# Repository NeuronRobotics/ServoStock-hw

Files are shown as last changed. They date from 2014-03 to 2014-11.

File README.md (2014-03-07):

# Servo Stock Hardware Project#

## Download ##

Check out this repository and the Vitamins repository into the same working directory. 
This project will assume both repositories are in this same directory. 

$ cd ~/git/

$ git clone https://github.com/Technocopia/ServoStock-hw.git

$ git clone https://github.com/Technocopia/Vitamins.git

$ cd ServoStock-hw/ServoStock/

## Building ##

This project is built with a 3 copies of the print bed found in 

SingleAxisPrintBed.scad 

and one copy of

ExtruderPrintBed.scad

## Vitamins ##

The ServoStock uses standardized vitamin models found in the Vitamins project. These models refer to actual hardware that can not be printed. 

Parts lists can be found here:

https://docs.google.com/spreadsheet/ccc?key=0AvROWAz_jAGGdHdnakh3WWF6LXMtMFFtdWdrZkJVZVE&usp=drive_web#gid=3

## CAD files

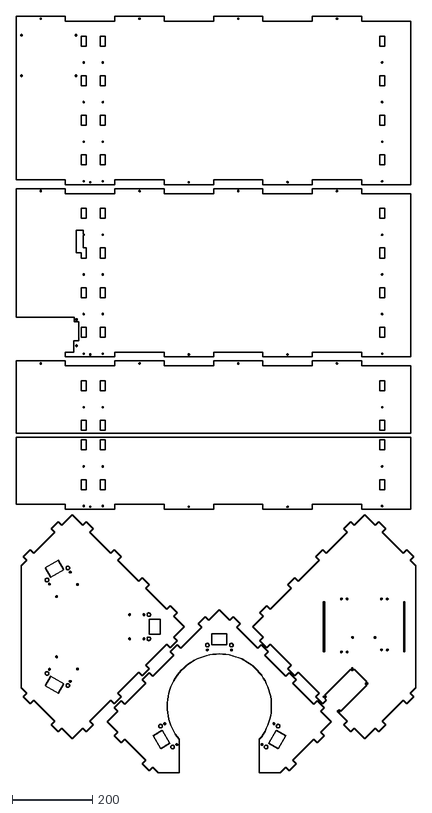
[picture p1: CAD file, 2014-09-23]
ServoStock/Cabinet/FullCabinetSidesHalfInch.dxf
997.3 x 1887.3

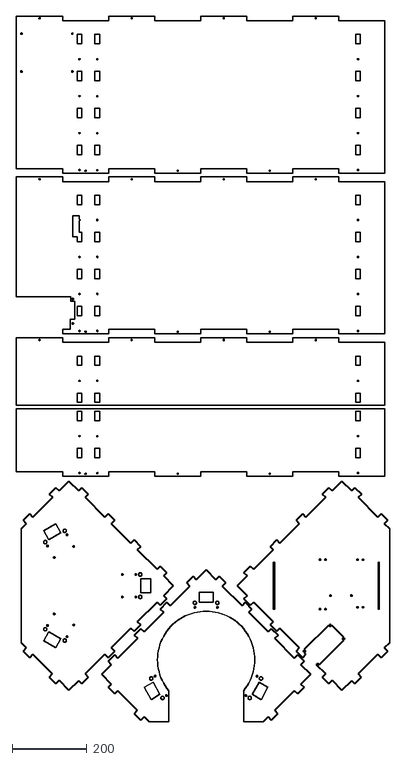
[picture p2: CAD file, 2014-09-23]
ServoStock/Cabinet/CabnetAssemblyCutSheetHalfInch.dxf
997.3 x 1887.3

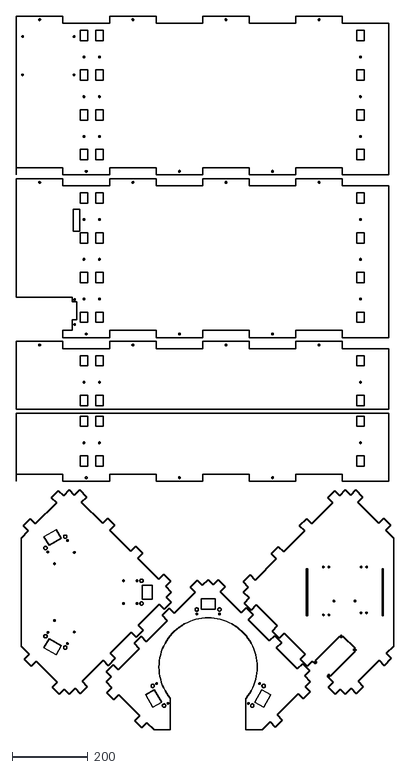
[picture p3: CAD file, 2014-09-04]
ServoStock/Cabinet/FullCabinetSides.dxf
997.3 x 1887.3

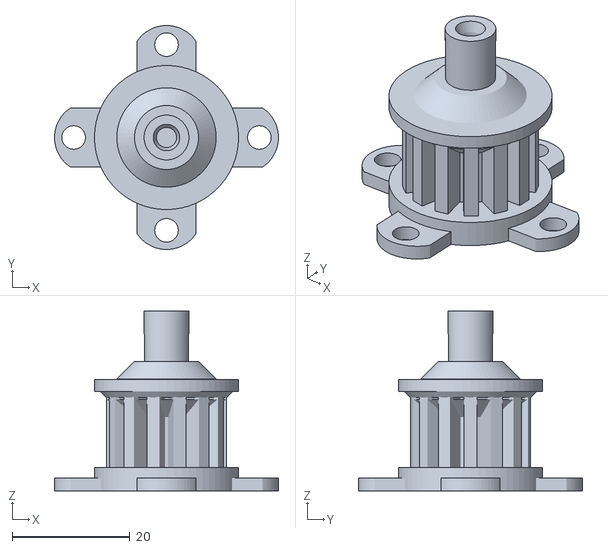
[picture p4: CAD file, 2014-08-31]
ServoStock/Axis/Pulley.stl
38.0 x 38.0 x 30.5

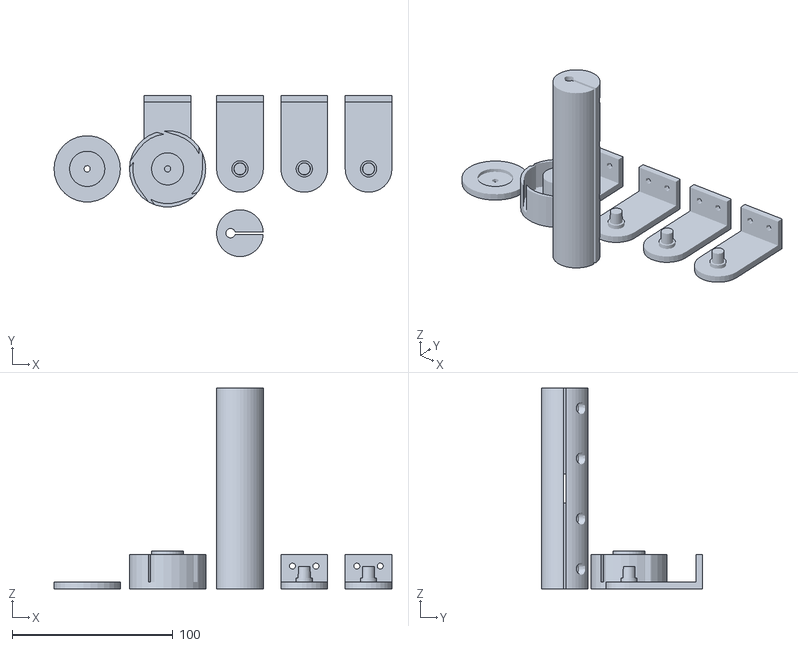
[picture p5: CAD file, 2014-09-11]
ServoStock/ContinuousBed/misc print bed.stl
210.2 x 100.2 x 124.9

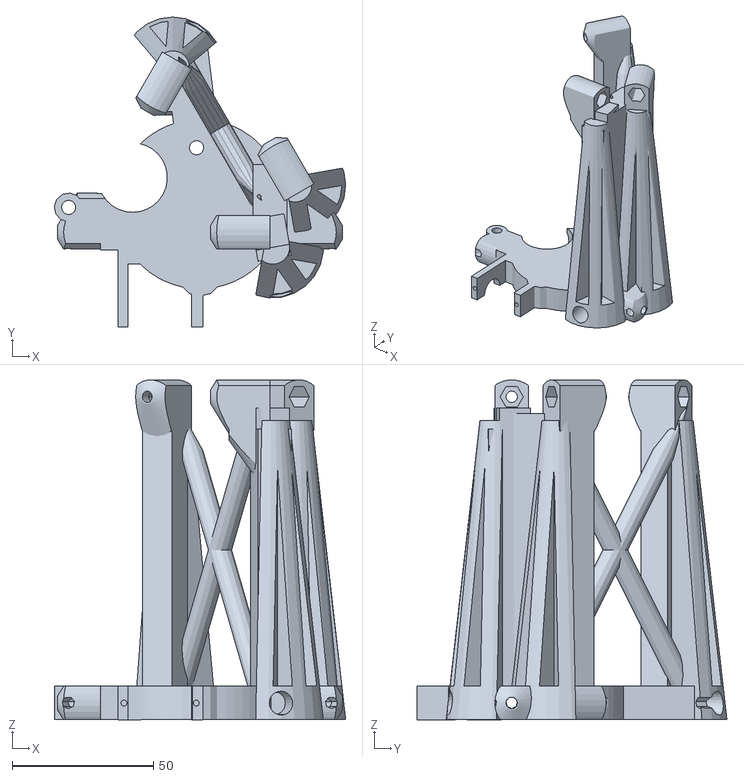
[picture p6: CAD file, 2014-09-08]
ServoStock/Extruder/Depricated/effector_wormtown.stl
103.2 x 109.8 x 120.4

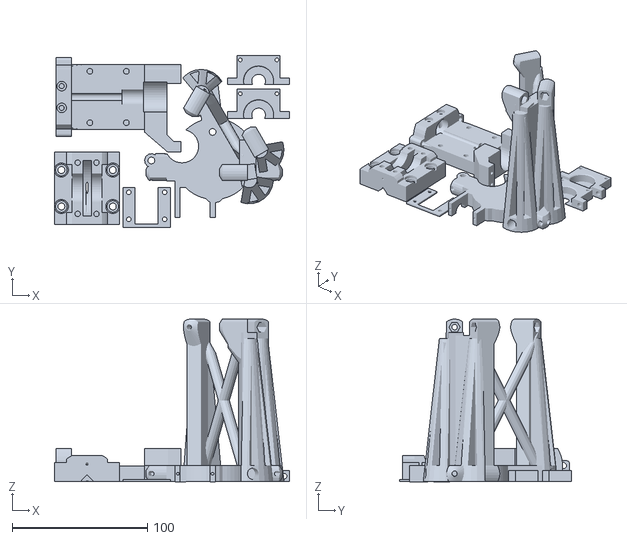
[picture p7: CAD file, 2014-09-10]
ServoStock/Extruder/EffectorPrintBed.stl
174.0 x 127.4 x 120.4

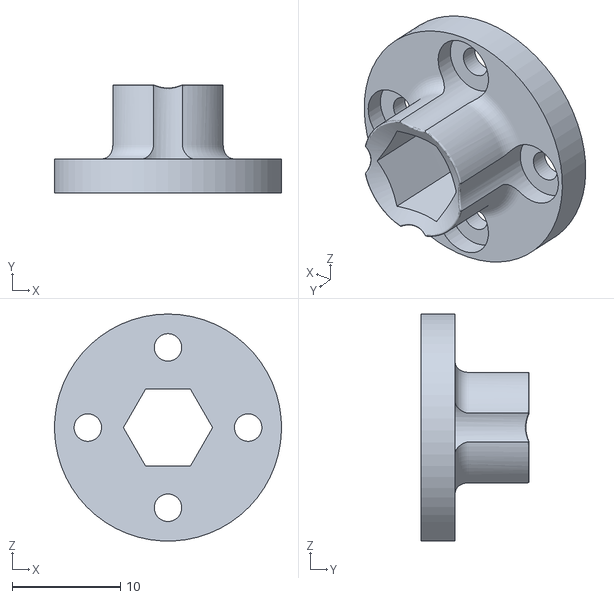
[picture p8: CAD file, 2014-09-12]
ServoStock/Extruder/printBed/hexbitadapter.STL
21.0 x 10.0 x 21.0

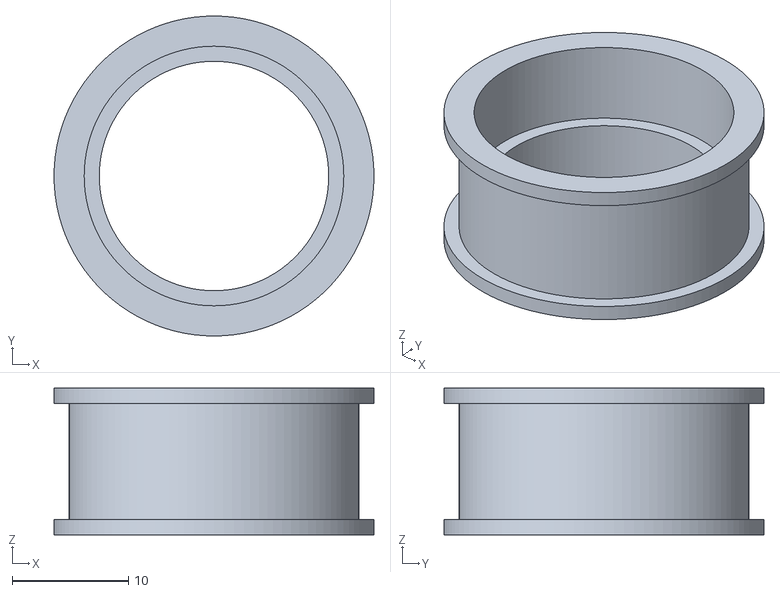
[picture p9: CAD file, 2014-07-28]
ServoStock/Axis/IdlerBearingClip.stl
27.5 x 27.5 x 12.6

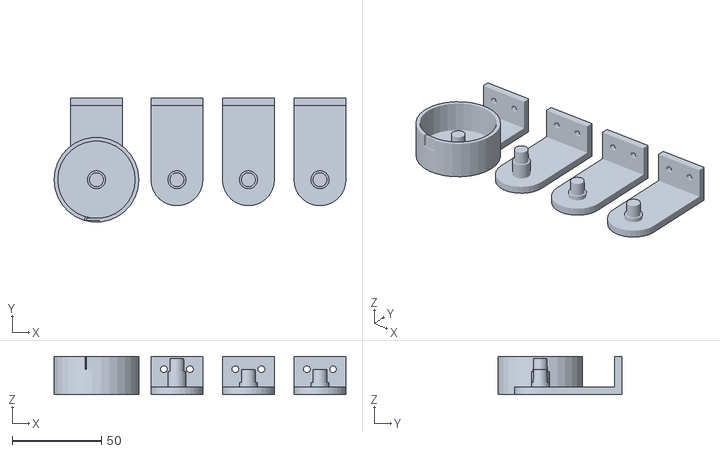
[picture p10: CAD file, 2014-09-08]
ServoStock/ContinuousBed/CanvasPulleyMount.stl
163.3 x 69.3 x 21.4

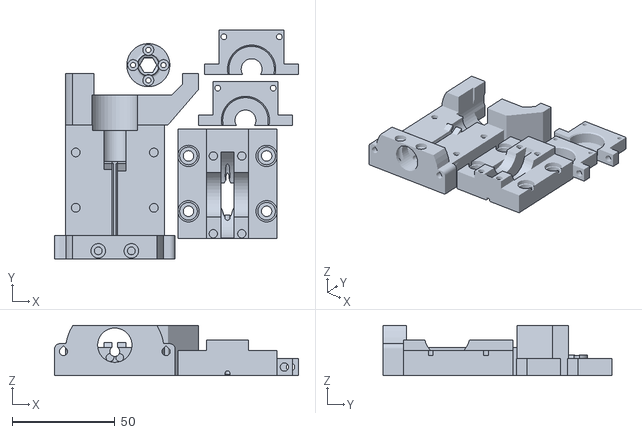
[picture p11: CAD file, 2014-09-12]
ServoStock/Extruder/printBed/EffectorPrintBed.stl
119.0 x 111.6 x 24.4

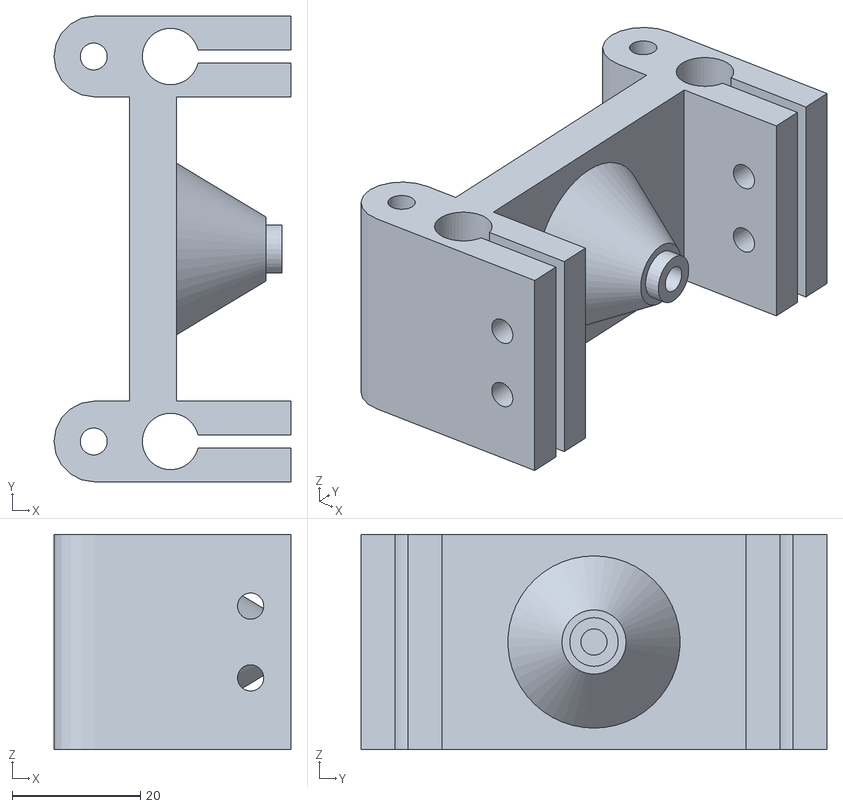
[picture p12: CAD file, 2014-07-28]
ServoStock/Axis/StructuralBearingMount2.stl
37.0 x 72.7 x 33.6

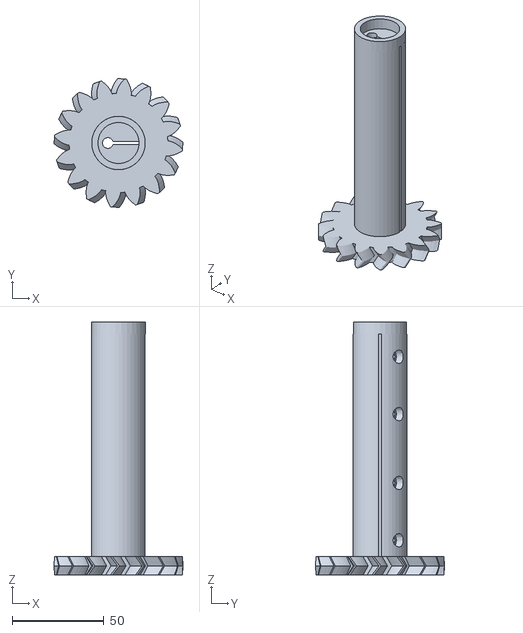
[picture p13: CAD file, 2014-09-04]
ServoStock/ContinuousBed/CanvasPulleyDriven.stl
70.0 x 70.0 x 137.7

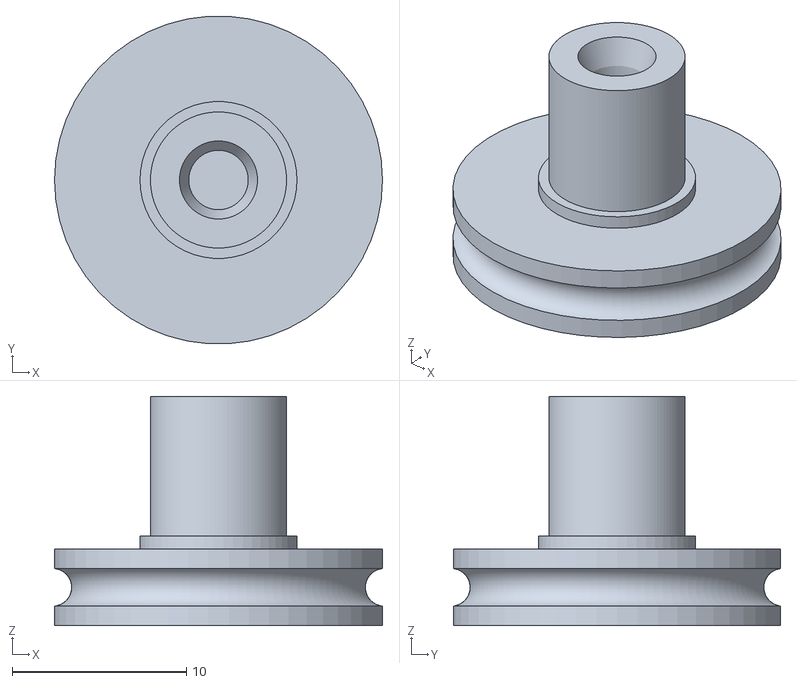
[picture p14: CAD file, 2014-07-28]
ServoStock/Extruder/Depricated/MKIIwheel.stl
18.8 x 18.8 x 13.2

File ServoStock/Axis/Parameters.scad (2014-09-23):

use <../../../Vitamins/Vitamins/Structural/SteelRod/8mm_Rod_Vitamin.scad>
use <../../../Vitamins/Vitamins/Structural/LinearBearings/LM8UU_Linear_Bearing_Vitamin.scad>
use <../../../Vitamins/Vitamins/Structural/SealedBearings/SealedBearing608_Vitamin.scad>
use <../../../Vitamins/Vitamins/Actuators/StandardServo/StandardServo_Vitamin.scad>
use <../../../Vitamins/Vitamins/Fasteners/ScrewsAsBolts/High_Low_Screw_As_Bolt_Vitamin.scad>
use <../../../Vitamins/Vitamins/Actuators/DrillPressSpring_Vitamin.scad>

function mm(i) = i*25.4; 

//Build dimensions (x,y,z)-- x, y and z of printable area, NOT of overall device

//z-rod length, diameter-- dependent on which rods you buy
//(bearing diameter is dependent on rod diameter)


function RodEndSpacing() = 108.5;// this is a magic number

//These are the values to use in the kinematics
function getFreeRodLength() = 203.82;
function getBaseRadius() = 140;
function getEffectorRadius() = 25;

// these are the parameters for the Case
rodLength = 775;

function MotorBracketHeight()= StandardServoLength()+StandardServoTolerance()*4+PlasticWidth()*2;
function getBedToBearingPlateHeight() =60-getCaseBoardThickness();
function getBedZHeight() = 150+getCaseBoardThickness();
//function getBedZHeight() =0;
//function getCaseBoardThickness() = 19.05;//3/4in
function getCaseBoardThickness() = 12.3;//1/2in
//function getCaseBoardThickness() = 3;//3/4in

function getPrintbedWidth() = 200;

//function getCaseHoleSize() = 4.5;// wood screw
function getCaseHoleSize() = 3.2;// 1/8 in hole
function forceNoTSlots() = true;
function getShortSideLength() = 180;
//function getCabinetHeight() = 800;// rod length minus feet height and board thickness

function getCabinetHeight() = getBedZHeight() + getBedToBearingPlateHeight() +rodLength;// rod length minus feet height and board thickness
function getCaseBoltHolePitch() =  getCabinetHeight()/4;
function extraSideLength()=140;
function getBaseSideLength() = getBaseRadius()*2+extraSideLength();
function getInnerPlateTabPitch() = (getBaseSideLength() - getCaseBoardThickness()*2)/4;



function ZrodSpacing()=RodEndSpacing()-LM8UULinearBearingDiam()*2-PlasticWidth()*4;
echo(ZrodSpacing());

//parametric of which hotend is being used (printerbot or bucha nozzle)

//stepper vs servo

//3 parameters (1 for each link) horizontal vs vertical

//paper is a parametric vitamin

//distance between link arms will be calculable based on radius of toolplate

//tolerances
//function LaserCutTolerance() = .02;
function 3dPrinterTolerance() = .4;



//the equation used for plastic width, it can of course be changed
function PlasticWidth()= (8mmRodDiameter()/2);
function SideWidth() = (8mmRodDiameter()+PlasticWidth());
echo(PlasticWidth());

//flashforge printable height
function FlashforgePrintableHeight()= 145;

//canvas pulley parameters
function CanvasPulleyLength()=FlashforgePrintableHeight()-608BallBearingHeight()*2-DrillPressSpringWidth()+2;
//CanvasPulleyLength should be(getBaseRadius()-60)*2, except that this is larger than the flashforge printable height. Therefore change the flashforge variable to this when we have a printer that can print a taller part.

function CanvasPulleyWidth()=HiLoBoltLength()*1.3;
echo(CanvasPulleyWidth());
function CanvasPulleySeperation()=100; //fairly arbitrary seperation between active and idler pullies
function HerringboneMotorMountLength()=StandardServoLength()+HiLoBoltHeadDiameter()*2; //length of the motor mount when the herringbone gear is used

//canvas pulley herringbone gear parameters
function CanvasGearPitch()=700;
function CanvasPulleyTeeth()=16;
function CanvasPulleyGearRadius()=(CanvasPulleyTeeth()*CanvasGearPitch()/180)/2;
function CanvasDriverTeeth()= 8;
function CanvasPulleyDriverRadius()=(CanvasDriverTeeth()*CanvasGearPitch()/180)/2;
function CanvasPulleyGearOffsetAngle()=25;
function CanvasPulleyMotorMountOffset()=sin(90-CanvasPulleyGearOffsetAngle())*(CanvasPulleyGearRadius()+CanvasPulleyDriverRadius());

//this is because there is a lot of torque on the printer bed components
function PrinterBedPlasticWidth()=PlasticWidth()*1.5;

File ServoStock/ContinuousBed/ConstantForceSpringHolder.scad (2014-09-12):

use <../Axis/Parameters.scad>
use <CanvasPulley.scad>
use <CanvasPulleyWormDriver.scad>
use <../../../Vitamins/Vitamins/Fasteners/Screws/High_Low_Screw_Vitamin.scad>
use <../../../Vitamins/Vitamins/Structural/SealedBearings/SealedBearing608_Vitamin.scad>
use <../../../Vitamins/Vitamins/Actuators/DrillPressSpring_Vitamin.scad>

module setFrame(){
	
	translate([DrillPressSpringOuterDiameter()/2,0,PlasticWidth()])
	{
		rotate([0,0,90])
		{
			children();
		}
	}
}

module ConstantForceSpringHolderFacer()
{
	translate([0,-1,0])
	{
		rotate([0,-78,0])
		{
			cube([CanvasPulleyEffectiveHeight()*1.5,PrinterBedPlasticWidth()+2,CanvasPulleyEffectiveHeight()]);
		}
	}
}


module ConstantForceSpringHolder()
{
	difference()
	{
		translate([-DrillPressSpringOuterDiameter()/2,0,-CanvasPulleyEffectiveHeight()])
		{
			union()
			{
				difference()
				{
					translate([-DrillPressSpringOuterDiameter()/4,0,0])
					{
						cube([DrillPressSpringOuterDiameter()*1.5, PrinterBedPlasticWidth(),CanvasPulleyEffectiveHeight()]);
					}
					translate([-DrillPressSpringOuterDiameter()/4,0,0])
					{
						ConstantForceSpringHolderFacer();
					}
					translate([DrillPressSpringOuterDiameter()*1.5-DrillPressSpringOuterDiameter()/4,0,0])
					{
						mirror([1,0,0])
						{
							ConstantForceSpringHolderFacer();
						}
					}
				}
				translate([-DrillPressSpringOuterDiameter()*.5/2, 0, 0])
				{
					cube([DrillPressSpringOuterDiameter()*1.5,PlasticWidth()+608BallBearingHeight()*4/3+DrillPressSpringWidth(), PrinterBedPlasticWidth()]);
				}
				translate([0,PlasticWidth(),CanvasPulleyEffectiveHeight()])
				{	
					translate([DrillPressSpringOuterDiameter()/2,-PlasticWidth(),0])
					{
						rotate([-90,0,0])
						{
							difference()
							{
								cylinder(r=(DrillPressSpringOuterDiameter()+PlasticWidth())/2, h=PrinterBedPlasticWidth()+608BallBearingHeight()*4/3+DrillPressSpringWidth());
								translate([0,0,PrinterBedPlasticWidth()])
								{
									cylinder(r=DrillPressSpringOuterDiameter()/2, h=PlasticWidth()+608BallBearingHeight()*4/3+DrillPressSpringWidth());		
								}
								for (i = [0:72:359])
								{ 
									translate([0,0,PrinterBedPlasticWidth()-PlasticWidth()])
									{
										rotate([0,0,i])
										{
											setFrame(){
											{
												cube([DrillPressSpringOuterDiameter()/2, 2, 18]);
											}
										}
									}
								}
							}	
						}
							difference()
							{
								cylinder(r=10, h=PlasticWidth()+608BallBearingHeight()*4/3+DrillPressSpringWidth()+PlasticWidth()/2);
								translate([0,0,PlasticWidth()+608BallBearingHeight()*4/3+DrillPressSpringWidth()+PlasticWidth()/2-HiLoScrewLength()])
								{
									cylinder(r=HiLoScrewDiameter(.3)/2, h=HiLoScrewLength()+1, $fn=20);	
								}	
							}	
						}			
					}
				}
			}
		}	
		translate([DrillPressSpringOuterDiameter()*1.5/2.5,(PrinterBedPlasticWidth()+608BallBearingHeight()*4/3+DrillPressSpringWidth())/2,-CanvasPulleyEffectiveHeight()+PrinterBedPlasticWidth()])
		#HiLoScrew();
		translate([-DrillPressSpringOuterDiameter()*1.5/2.5,(PrinterBedPlasticWidth()+608BallBearingHeight()*4/3+DrillPressSpringWidth())/2,-CanvasPulleyEffectiveHeight()+PrinterBedPlasticWidth()])
		#HiLoScrew();
	}
}




ConstantForceSpringHolder();


module ConstantForceSpringCap()
{
	difference()
	{
		cylinder(r=DrillPressSpringOuterDiameter()/2-1, h=PlasticWidth());
		cylinder(r=11, h=PlasticWidth()/2);
		cylinder(r=HiLoScrewDiameter(.6)/2, h=PlasticWidth());
	}
}


//translate([0,26,0])
//rotate([-90,0,0])
//ConstantForceSpringCap();

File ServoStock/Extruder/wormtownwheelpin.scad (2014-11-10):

// This is the pin for the encoder wheel.  when printing, call '3dPrinterTolerance in the module as zero.  add .4-.8 for subtractions in the wheel and elsewhere.

$fn=100;

use <wormtownwheel.scad>
use <../../../Vitamins/Vitamins/Sensors/Encoders/EncoderMagnet_Vitamin.scad>
use <../../../Vitamins/Vitamins/Structural/SealedBearings/SealedBearing608_Vitamin.scad>

function pinheight()=(2*608BallBearingHeight(.4))+wheelthickness(.4);

module wormpin(3dPrinterTolerance){
	difference(){
		cylinder (r=608BallBearingInnerDiam(.4)/2,h=pinheight());
		translate([0,0,pinheight()-MagnetLength()+.1]){
			EncoderMagnet(true,.4);
		}
		translate([608BallBearingInnerDiam(.4)/3,-608BallBearingInnerDiam(.4),-.5]){
			cube([608BallBearingInnerDiam(.4)*2,608BallBearingInnerDiam(.4)*2,pinheight(.4)+1]);
		}
	}
}

wormpin();
//test

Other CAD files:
ServoStock/Extruder/Depricated/effector.stl
ServoStock/Extruder/printBed/hex bit adapterWPI.STL
ServoStock/Axis/Rod.stl
ServoStock/ContinuousBed/CanvasPulleyPrintBed.stl
ServoStock/Extruder.scad
ServoStock/Axis/Clips.scad
ServoStock/Axis/IdlerBearingClip.scad
ServoStock/Axis/IdlerBearingPlug.scad
ServoStock/Axis/Pulley.scad
ServoStock/Axis/Rod.scad
ServoStock/Axis/RodEndClips.scad
ServoStock/Axis/SingleAxisPrintBed.scad
ServoStock/Axis/Slider.scad
ServoStock/Axis/Slider.stl
ServoStock/Axis/StructuralBearingMount2.scad
ServoStock/Axis/StructuralFeet.scad
ServoStock/Cabinet/CabinetSides.scad
ServoStock/Cabinet/CabinetTopSheet.scad
ServoStock/Cabinet/CabnetAssemblyCutSheet.scad
ServoStock/ContinuousBed/CanvasPulley.scad
ServoStock/ContinuousBed/CanvasPulley.stl
ServoStock/ContinuousBed/CanvasPulleyAssembly.scad
ServoStock/ContinuousBed/CanvasPulleyDriver.scad
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

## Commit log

2014-01-17 Rearranged the local repository to get everything in the right place
    This allowed the import script to just pull one top level directory each
    [0.dxf, 1.dxf, 2.dxf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]
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2014-02-02 Adding the readme and starting to fix the paths
    [Header.scad, Parameters.scad]
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2014-02-02 Changed the file paths
    I changed the path to get to the Vitamins directory. This fits the new
    GitHub directory structure.
    [BearingCap.scad, Clips.scad, Extruder.scad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]
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2014-02-02 Fixing the paths to the vitamins
    [BearingCap.scad, Clips.scad, ExtruderIdlerWheel.scad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]
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2014-02-02 Added the Rod to the single axis print bed
    I added the single axis print bed.
    [AdamRod.scad, Extruder.scad, Parameters.scad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]
2014-02-03 Added the cabnet files
    This folder will hold the sources for the support cabnet of the
    servostock.
    [CabnetSheet.scad]
2014-02-09 Added the Extruder plate and shored up the rods
    [Rod.scad, effector.scad]
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2014-02-11 Added the slots to get the screwdriver in to the rod
    [Rod.scad]
2014-02-14 Fairly certain this is the final form of the extruder. Spacing of the end effector connection screw holes may need fine adjustment later.
    [ExtruderMKII.scad]
2014-02-15 mated the extruder with the effector so the screw holes line up.
    [ExtruderMKII.scad, effector.scad]
2014-02-17 increased depth of hot end hole in extruder to increase print volume.
    [ExtruderMKII.scad, effector.scad]
2014-02-17 Adding the vertical configuration of the base plate
    [effector.scad]
2014-02-17 Vertical bars working, need to shrink plate size
    [effector.scad]
2014-02-18 I have made the vertical end effector parameterized
    All of the critial dimentions are keyed off the kinematics inputs.
    [Parameters.scad, effector.scad]
2014-02-18 Added a slot to get the nut into the bottom of the end effector
    [effector.scad]
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2014-02-18 Added the Vertical brace to the slider
    By putting both sets I do not have to make it more complex. Its a little extra plastic, but more universal.
    [RodEndClips.scad, Slider.scad]
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2014-02-28 minor size reductions to extruder, beginning work on anti-jamming section soon.
    [ExtruderMKII.scad]
2014-03-05 improved extruder to reduce the risk of filament crimping. hopefully final iteration ready for the full spectrum of testing.
    [ExtruderMKII.scad]
2014-03-06 Fixed reference to rod end clips vitamin
    [RodEndClips.scad]
2014-03-13 removed conflicting corner, work on autocalibration coming soon.
    [ExtruderMKII.scad]
2014-04-08 #1 This is the .dxf to use for the holes for the feet.
    [CabnetSheet.scad, FeetOutline.dxf]
2014-04-22 Adjusted the height of the pilar on the vertical connector
    [effector.scad]
2014-04-22 Make the default for the slider the attachment for the belts
    [Slider.scad]
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2014-04-22 Updated the support of the for the bracket
    [RodEndClips.scad, Slider.scad, Slider.stl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]
2014-05-01 Filleted some corners of extruder body to reduce lifting, fine adjustment of top half to fit the bearing.
    [ExtruderMKII.scad, ExtruderPrintBed.scad]
2014-05-03 Improved printability of extruder top. Reduced risk of lower pin snapping.
    [ExtruderMKII.scad]
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2014-05-19 Updated the effector
    The effector is now thicker and has bracing for the vertical arms
    [Pulley.stl, effector.scad, effector.stl]
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2014-05-26 Making the cabnet start correctly
    [CabnetSheet.scad]
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2014-05-26 fixes compilation
    [Slider.scad]
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2014-05-28 Fixed therecursive placement problem. Structural Feet working
    [CabnetSheet.scad, Clips.scad, effector.stl]
2014-05-28 Fixed the feet interface with a simplified 2d gometry version
    [CabnetSheet.scad, Clips.scad, FeetOutline.dxf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]
2014-05-28 created encoder keepaway for extruder, extended the shaft of the wheel.
    [ExtruderEncoderKeepaway.scad, ExtruderMKII.scad, MKIIwheel.scad]
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2014-05-29 Adding the second set of bearing mounts to the slider
    [Slider.scad]
2014-05-29 Fixed mount gap
    [Slider.scad]
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2014-06-17 completed latest round of improvements to extruder. improved strength of hinge on bottom half.
    [ExtruderMKII.scad]
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2014-06-18 widened the hole for the encoder wheel through the top of the extruder.
    [ExtruderMKII.scad]
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2014-06-21 fixing the support around the new pilar
    [effector.scad]
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2014-06-23 improved spacing of parts on print bed to avoid contact.
    [SingleAxisPrintBed.scad]
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2014-06-26 improved draft on mkII wheel, hopefully fixing magnet alignment issue.
    [MKIIwheel.scad]
2014-06-29 fixed some typos, made a pulley for canvas
    [BusinessCardHolder.scad, CabinetSheet.scad, CanvasPulley.scad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]
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2014-07-01 I removed the outer clip part, speeds assemble and has no function in stiffness.
    [RodEndClips.scad]
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2014-07-02 Rods use the highLow loose fit hole
    [Rod.scad]
2014-07-02 Making the mount holes larg enough for the bolts to pass through
    [RodEndClips.scad]
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2014-07-07 Making the clearence hole on structural feet to allow for easy assembling
    [StructuralFeet.scad]
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2014-07-14 Fixing the captured nut rectangle size
    [effector.scad]
2014-07-14 Making the Xl pulley the correct width
    [IdlerBearingClip.scad, Pulley.stl]
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2014-07-22 moved the brace rods away from the interference path
    [effector.scad]
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2014-07-29 Fixed the bed dimentions
    [CabinetSheet.dxf, FeetOutline.dxf, FullCabenitSides.dxf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]
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2014-08-01 fixing the sheet size allignment
    [CabinetSides.scad]
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2014-08-04 Organized references, fixed infinite loops
    [3dBedPlate.scad, CabinetTopSheet.scad, CanvasPulley.scad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]
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2014-08-25 fixed the pulley dimentions
    [Pulley.scad]
2014-08-25 Fixed the belt ride up problem
    [IdlerBearingClip.scad]
2014-08-25 fixed the rods to the print bed
    [SingleAxisPrintBed.scad]
2014-08-25 fixing the timing belt name in include
    [Slider.scad]
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2014-08-27 Fixing the pully flange dimentions
    [Pulley.scad]
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2014-08-27 making the bearing plug fit the threads as pass through not threaded
    [IdlerBearingPlug.scad]
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2014-08-28 fixed the pulley magner recess
    [Pulley.scad]
2014-08-28 Moved the rods into the middle of the print bed to avoid lift up
    [SingleAxisPrintBed.scad]
2014-08-28 removing references to missing part
    [Header.scad, SingleAxisPrintBed.scad, StructuralFeet.scad]
2014-08-28 made the holes for the tabs not an interference cut.
    [CabinetSides.scad, CabinetTopSheet.scad, Parameters.scad]
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2014-09-02 fixing the pully pin length
    [Pulley.scad, effector.stl]
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2014-09-08 Shrinking the size of the bite hole for the structural bearing mount
    [IdlerBearingPlug.scad, StructuralBearingMount2.scad]
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2014-09-23 updates to hex bit adapter
    finished defining all major features, need to go back in when servo horn
    vitamin is created. four screw holes connect the adapter to the horn,
    which holds the hex bit.
    in other news, I miss fillets. Fillets make everything smooth and
    friendly.
    [hexbitadapter.scad]
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2014-09-25 wheel rev 1 complete
    updated screw positions, counterbores for screwheads, and height of
    center column to improve o-ring contact.
    [wormtownwheel.scad, wormtownwheelpin.scad]
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2014-09-26 updates to wheel
    added 'wheelthickness' function to use for the top plate, and made a
    print bed for the wheel halves.
    [wormtownwheel.scad]
2014-09-26 tweaks and added bracket
    updated wheel to fully enclose the length of a 1/2" hi lo screw. Wheel
    is now considered finished. Parameterized pin more precisely to
    thickness of wheels and two bearings. Also started working on the
    mounting bracket for the wheel.
    [wormtownbracket.scad, wormtownwheel.scad, wormtownwheelpin.scad]
2014-09-29 updates to bracket
    turned the wheel radius into a function for use in the bracket, made
    encoder mount for the bracket.
    [wormtownbracket.scad, wormtownwheel.scad]
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2014-09-30 finished bracket rev1
    fixed boolean to add or remove encoder mount, aligned all components.
    [wormtownbracket.scad]
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2014-10-01 added tolerance to wheel pin
    adding tolerance to make the holes in the wheel fit the pin better.
    [wormtownwheelpin.scad]
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2014-10-31 made the belt holder bigger
    made the belt holder bigger. This removes issue with the belt not
    holding.
    [Slider.scad]
2014-11-10 fixed the pin
    [effector.scad, wormtownwheelpin.scad]
